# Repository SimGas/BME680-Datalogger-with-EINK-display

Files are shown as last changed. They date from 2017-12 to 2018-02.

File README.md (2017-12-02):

# BME680-Datalogger-with-EINK-display
Datalogger with BME680-Sensor, EINK Display, RTC and µSD-Storage

This project features a Arduino based datalogger reading temperature, relative humidity, pressure and IAQ values from a Bosch BME680 sensor. It displays the data at a 2.9 inch waveshare e-ink display using olikraus's u8g2 lib. The data is being synchronized with a DS3231 RTC and stored at a micro SD-Card.

The whole system runs on a adafruit feather M0 board

Please consider that this project is in a very early development status. I haven't completed the program code yet and I've just ordered the Mainboard.
If you want to make your own copy of this project, please contact me for information about recent unpublished changes.

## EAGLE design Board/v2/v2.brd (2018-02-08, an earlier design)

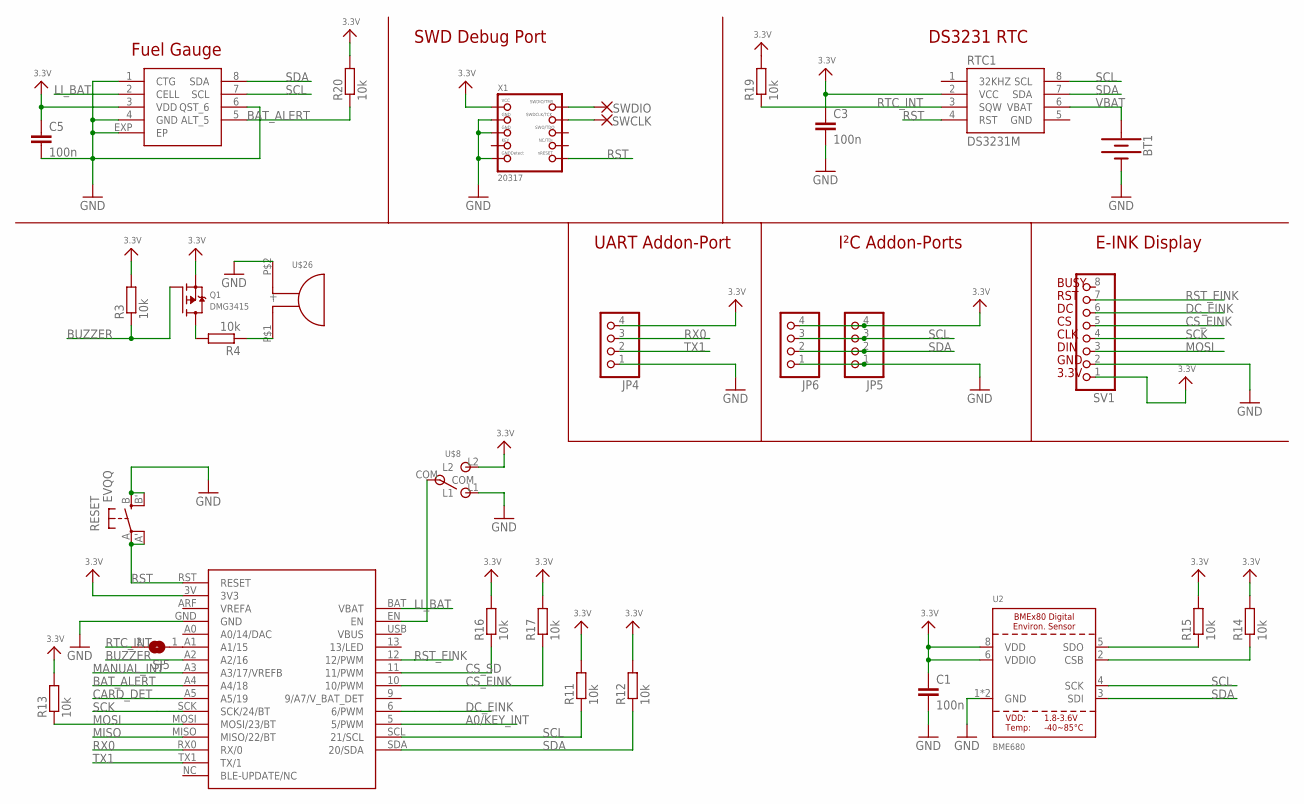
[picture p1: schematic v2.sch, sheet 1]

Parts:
BT1: BATTERY-12MM_SMD; BATTCON_12MM
C1, C3, C5: 100n; C0805
JP4, JP5, JP6: PINHD-1X04_2.54; 1X04
Q1: DMG3415; SOT23-WIDE
R3, R4, R11, R12, R13, R14, R15, R16, R17, R19, R20: 10k; R0805
RESET: EVQQ; EVQ-Q2
RTC1: DS3231M; SO08
SJ5: SOLDERJUMPERCLOSED; SOLDERJUMPER_CLOSEDWIRE
SV1: PINHD-1X08_2.54; 1X08
SWCLK: SMD1,27-2,54
SWDIO: SMD1,27-2,54
U2: BME680; BME280
U$8: MSK-12C02_SMD_SPDT_SWITCH; MSK-12C02
U$15: FEATHER_M0
U$26: DTS402G1; DET402G1
U$33: MAX17043; DFN-2X3
X1: 20317; 2X05_1.27MM_BOX_POSTS

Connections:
3.3V: C1.1, C3.1, C5.1, JP4.4, JP5.4, JP6.4, Q1.2 (S), R3.2, R11.2, R12.2, R13.2, R14.2, R15.2, R16.2, R17.2, R19.2, R20.2, RTC1.2 (VCC), SV1.1, U2.6 (VDDIO), U2.8 (VDD), U$8.L2, U$15.3V (3V3), U$33.3 (VDD), X1.1 (VCC); also elsewhere on the board
A0/KEY_INT: U$15.5 (5/PWM); also elsewhere on the board
BAT_ALERT: R20.1, U$15.A4 (A4/18), U$33.5 (ALT_5)
BUZZER: Q1.1 (G), R3.1, U$15.A2 (A2/16)
CARD_DET: U$15.A5 (A5/19); also elsewhere on the board
CS_EINK: R17.1, SV1.5, U$15.10 (10/PWM)
CS_SD: R16.1, U$15.11 (11/PWM); also elsewhere on the board
DC_EINK: SV1.6, U$15.6 (6/PWM)
EN: U$8.COM, U$15.EN
GND: BT1.GND (-), C1.2, C3.2, C5.2, JP4.1, JP5.1, JP6.1, RESET.B (S), RESET.B' (S1), RTC1.5 (GND), SV1.2, U2.1 (GND), U2.7 (GND), U$8.L1, U$15.GND, U$26.P$2 (-), U$33.1 (CTG), U$33.4 (GND), U$33.6 (QST_6), U$33.EXP (EP), X1.3 (GND), X1.5 (GND), X1.9 (GNDDETECT); also elsewhere on the board
LI_BAT: U$15.BAT (VBAT), U$33.2 (CELL)
MANUAL_INT: U$15.A3 (A3/17/VREFB); also elsewhere on the board
MISO: U$15.MISO (MISO/22/BT); also elsewhere on the board
MOSI: R13.1, SV1.3, U$15.MOSI (MOSI/23/BT); also elsewhere on the board
unnamed: R14.1, U2.2 (CSB)
unnamed: SJ5.1, U$15.A1 (A1/15)
unnamed: Q1.3 (D), R4.2
unnamed: R4.1, U$26.P$1 (+)
unnamed: R15.1, U2.5 (SDO)
unnamed: SWDIO.1, X1.2 (SWDIO)
unnamed: SWCLK.1, X1.4 (SWDCLK)
RST: RESET.A, RESET.A' (P1), RTC1.4 (RST), U$15.RST (RESET), X1.10 (NRESET)
RST_EINK: SV1.7, U$15.12 (12/PWM)
RTC_INT: R19.1, RTC1.3 (SQW), SJ5.2
RX0: JP4.3, U$15.RX0 (RX/0)
SCK: SV1.4, U$15.SCK (SCK/24/BT); also elsewhere on the board
SCL: JP5.3, JP6.3, R11.1, RTC1.8 (SCL), U2.4 (SCK), U$15.SCL (21/SCL), U$33.7 (SCL); also elsewhere on the board
SDA: JP5.2, JP6.2, R12.1, RTC1.7 (SDA), U2.3 (SDI), U$15.SDA (20/SDA), U$33.8 (SDA); also elsewhere on the board
TX1: JP4.2, U$15.TX1 (TX/1)
VBAT: BT1.PWR@1 (+), RTC1.6 (VBAT)

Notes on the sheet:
3.3V
GND
DIN
CLK
RST
BUSY
Fuel Gauge
SWD Debug Port
DS3231 RTC
E-INK Display
I²C Addon-Ports
UART Addon-Port

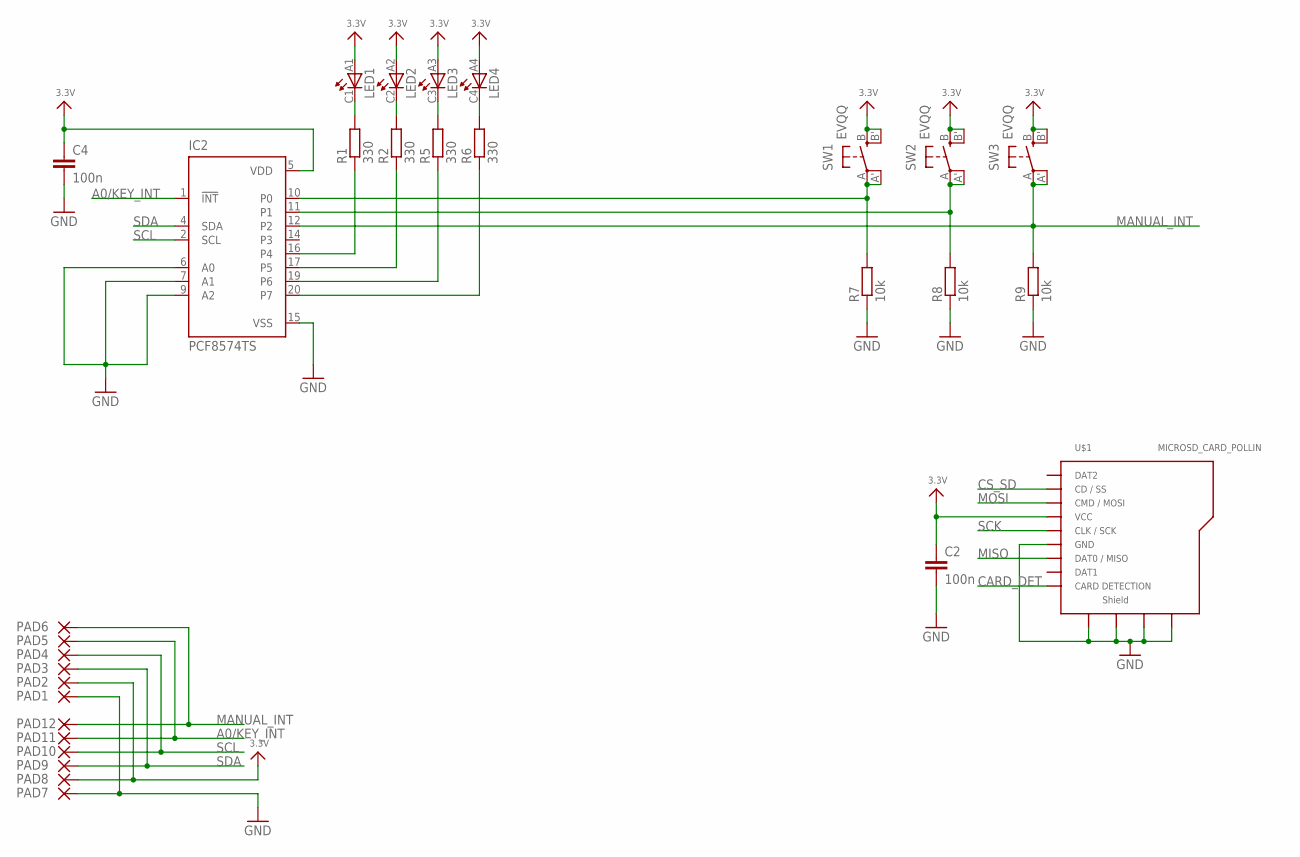
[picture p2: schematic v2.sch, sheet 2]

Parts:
C2, C4: 100n; C0805
IC2: PCF8574TS; SSOP20
PAD1, PAD2, PAD3, PAD4, PAD5, PAD6, PAD7, PAD8, PAD9, PAD10, PAD11, PAD12: SMD1,27-2,54
R1, R2, R5, R6: 330; R0805
R7, R8, R9: 10k; R0805
SW1, SW2, SW3: EVQQ; EVQ-Q2
U$1: MICROSD_CARD_POLLIN; MR**-AP*03**
U$5: LED_LIGHTGUIDE; LPA-C041301S-X

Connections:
3.3V: C2.1, C4.1, IC2.5 (VDD), PAD2.1, PAD8.1, SW1.B (S), SW1.B' (S1), SW2.B (S), SW2.B' (S1), SW3.B (S), SW3.B' (S1), U$1.VCC, U$5.A1, U$5.A2, U$5.A3, U$5.A4; also elsewhere on the board
A0/KEY_INT: IC2.1 (!INT), PAD5.1, PAD11.1; also elsewhere on the board
CARD_DET: U$1.CARD_DETECTION (CARD_D); also elsewhere on the board
CS_SD: U$1.DAT3/CS (CD/SS); also elsewhere on the board
GND: C2.2, C4.2, IC2.6 (A0), IC2.7 (A1), IC2.9 (A2), IC2.15 (VSS), PAD1.1, PAD7.1, R7.1, R8.1, R9.1, U$1.GND, U$1.SHD_1 (SHD1), U$1.SHD_2 (SHD2), U$1.SHD_3 (SHD3), U$1.SHD_4 (SHD4); also elsewhere on the board
MANUAL_INT: IC2.12 (P2), PAD6.1, PAD12.1, R9.2, SW3.A, SW3.A' (P1); also elsewhere on the board
MISO: U$1.DAT0 (DAT0/MISO); also elsewhere on the board
MOSI: U$1.CMD (CMD/MOSI); also elsewhere on the board
unnamed: IC2.16 (P4), R1.1
unnamed: IC2.17 (P5), R2.1
unnamed: IC2.10 (P0), R7.2, SW1.A, SW1.A' (P1)
unnamed: IC2.11 (P1), R8.2, SW2.A, SW2.A' (P1)
unnamed: IC2.19 (P6), R5.1
unnamed: IC2.20 (P7), R6.1
unnamed: R6.2, U$5.C4
unnamed: R5.2, U$5.C3
unnamed: R2.2, U$5.C2
unnamed: R1.2, U$5.C1
SCK: U$1.CLK (CLK/SCK); also elsewhere on the board
SCL: IC2.2 (SCL), PAD4.1, PAD10.1; also elsewhere on the board
SDA: IC2.4 (SDA), PAD3.1, PAD9.1; also elsewhere on the board

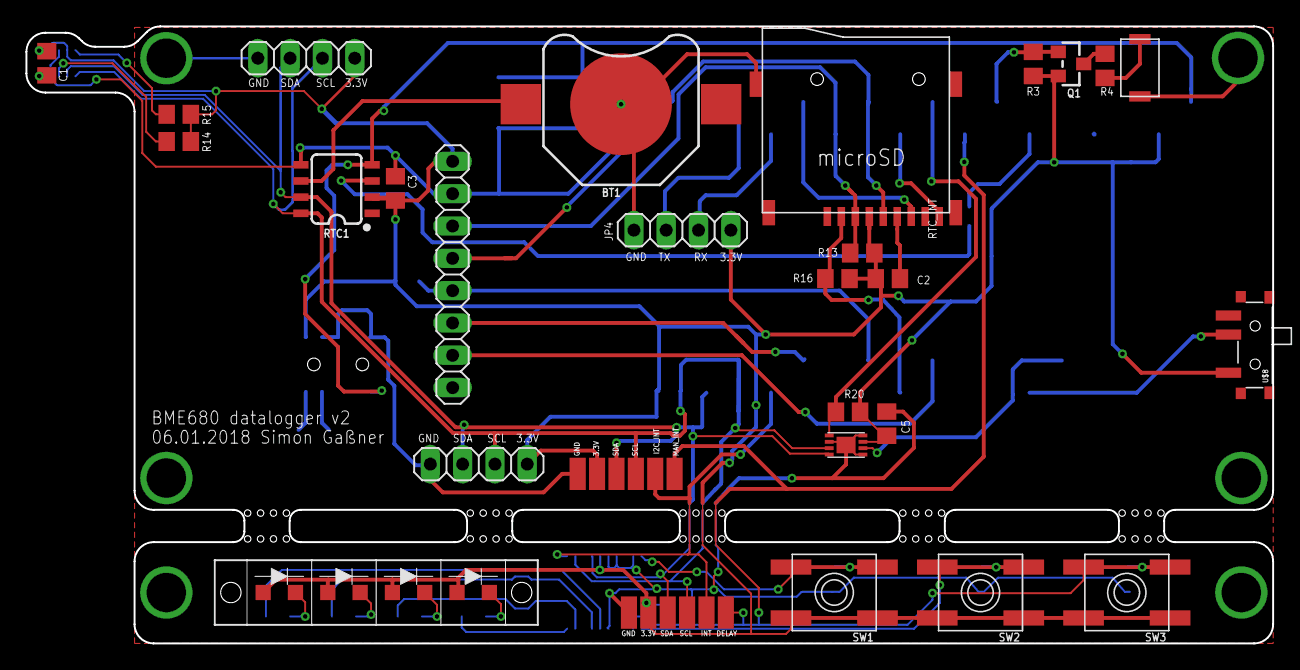
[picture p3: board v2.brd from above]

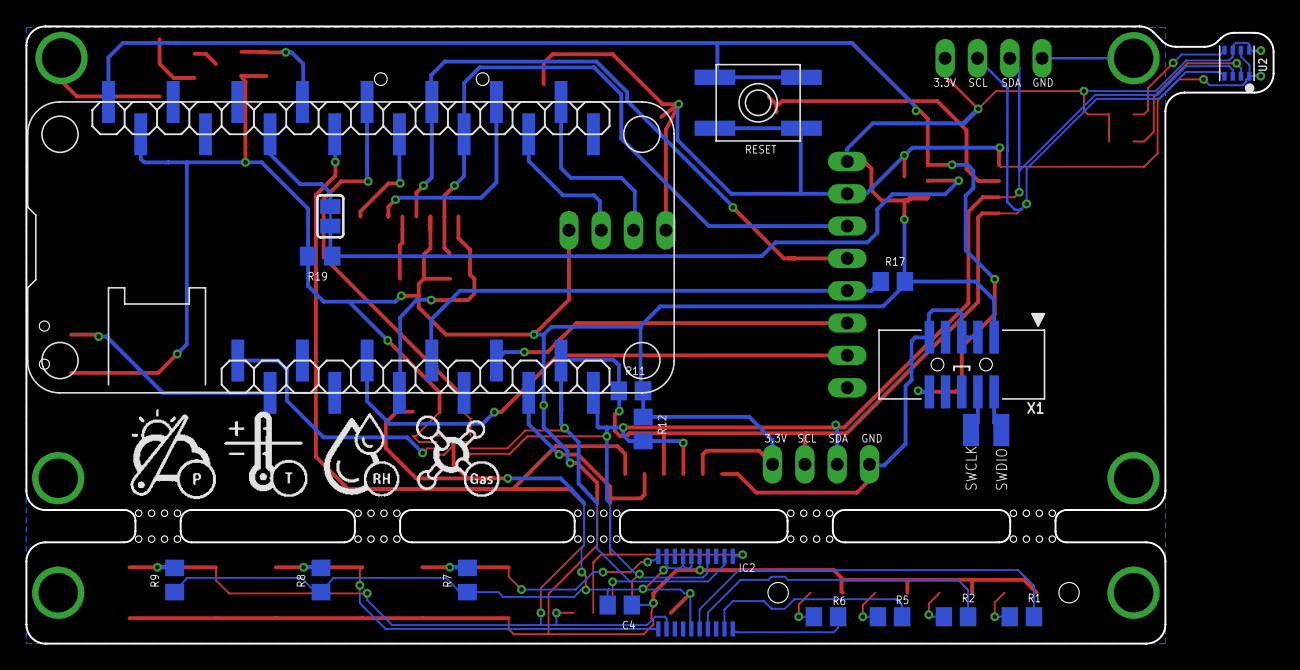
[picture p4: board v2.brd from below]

Board: 2 copper layers, 98.0 x 48.5 mm, 59 parts (20 on the bottom side), 40 nets.

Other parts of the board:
U$14: GASLOGO45MM; BME680_LOGO_30MM

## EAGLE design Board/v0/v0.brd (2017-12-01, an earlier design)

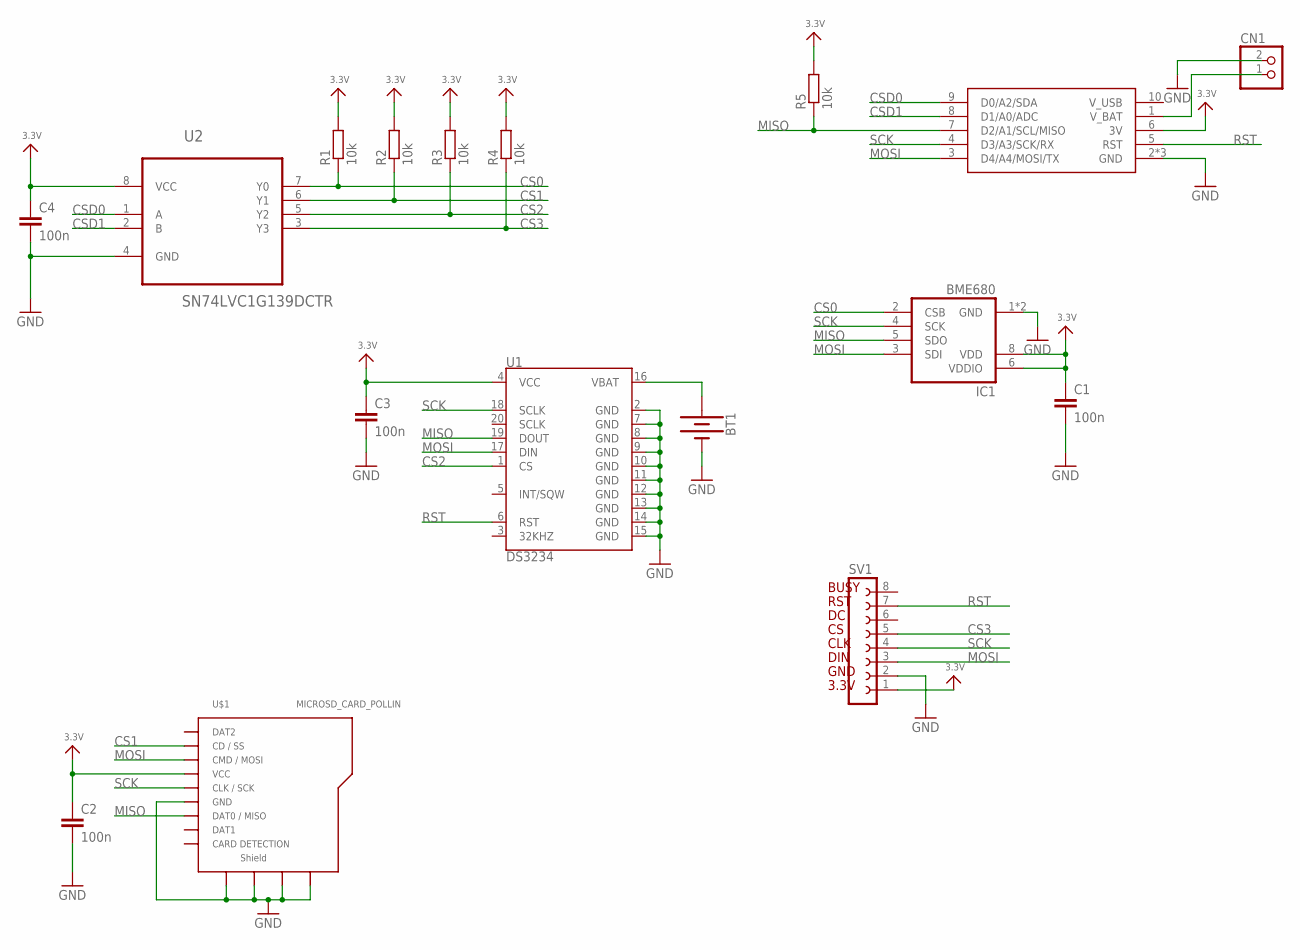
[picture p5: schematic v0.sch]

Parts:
BT1: BATTERY-12MM_SMD; BATTCON_12MM
C1, C2, C3, C4: 100n; C0805
CN1: JST_2PIN-SMT-RA; JST-PH-2-SMT-RA
IC1: BME680
R1, R2, R3, R4, R5: 10k; R0805
SV1: FE08-1; FE08
U1: DS3234; SO20-0.3
U2: SN74LVC1G139DCTR; SOP65P400X130-8N
U$1: MICROSD_CARD_POLLIN; MR**-AP*03**
U$8: TRINKET_M0

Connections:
3.3V: C1.1, C2.1, C3.1, C4.1, IC1.6 (VDDIO), IC1.8 (VDD), R1.2, R2.2, R3.2, R4.2, R5.2, SV1.1, U1.4 (VCC), U2.8 (VCC), U$1.VCC, U$8.6 (3V)
CS0: IC1.2 (CSB), R1.1, U2.7 (Y0)
CS1: R2.1, U2.6 (Y1), U$1.DAT3/CS (CD/SS)
CS2: R3.1, U1.1 (CS), U2.5 (Y2)
CS3: R4.1, SV1.5, U2.3 (Y3)
CSD0: U2.1 (A), U$8.9 (D0/A2/SDA)
CSD1: U2.2 (B), U$8.8 (D1/A0/ADC)
GND: BT1.GND (-), C1.2, C2.2, C3.2, C4.2, CN1.2 (1), IC1.1 (GND), IC1.7 (GND), SV1.2, U1.2 (GND), U1.7 (GND), U1.8 (GND), U1.9 (GND), U1.10 (GND), U1.11 (GND), U1.12 (GND), U1.13 (GND), U1.14 (GND), U1.15 (GND), U2.4 (GND), U$1.GND, U$1.SHD_1 (SHD1), U$1.SHD_2 (SHD2), U$1.SHD_3 (SHD3), U$1.SHD_4 (SHD4), U$8.2 (GND), U$8.11 (GND), U$8.12 (GND)
MISO: IC1.5 (SDO), R5.1, U1.19 (DOUT), U$1.DAT0 (DAT0/MISO), U$8.7 (D2/A1/SCL/MISO)
MOSI: IC1.3 (SDI), SV1.3, U1.17 (DIN), U$1.CMD (CMD/MOSI), U$8.3 (D4/A4/MOSI/TX)
unnamed: BT1.PWR@1 (+), U1.16 (VBAT)
RST: SV1.7, U1.6 (RST), U$8.5 (RST)
SCK: IC1.4 (SCK), SV1.4, U1.18 (SCLK), U$1.CLK (CLK/SCK), U$8.4 (D3/A3/SCK/RX)
V_BAT: CN1.1 (2), U$8.1 (V_BAT)

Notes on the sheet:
3.3V
GND
DIN
CLK
RST
BUSY

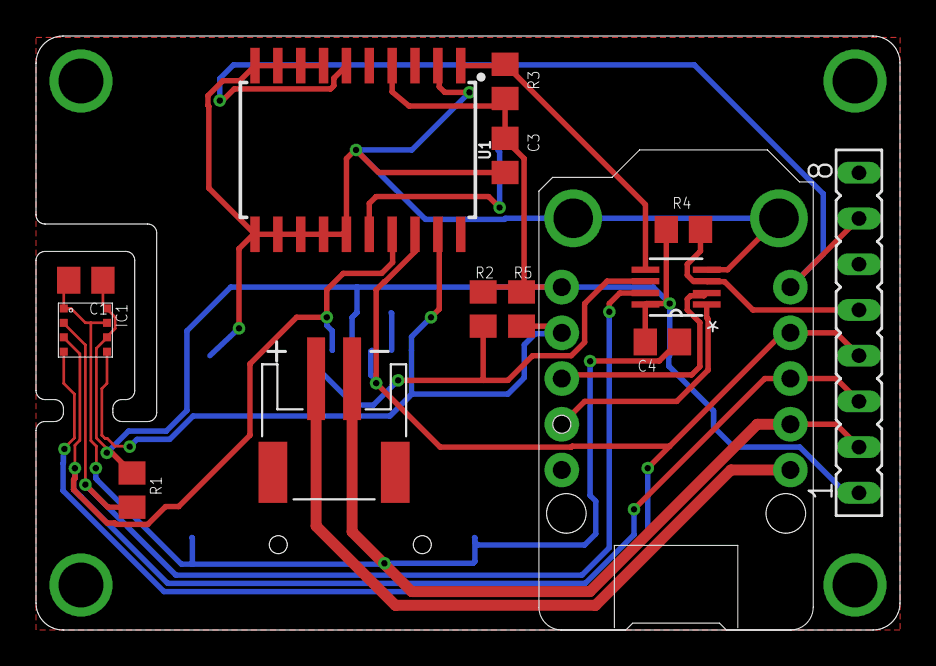
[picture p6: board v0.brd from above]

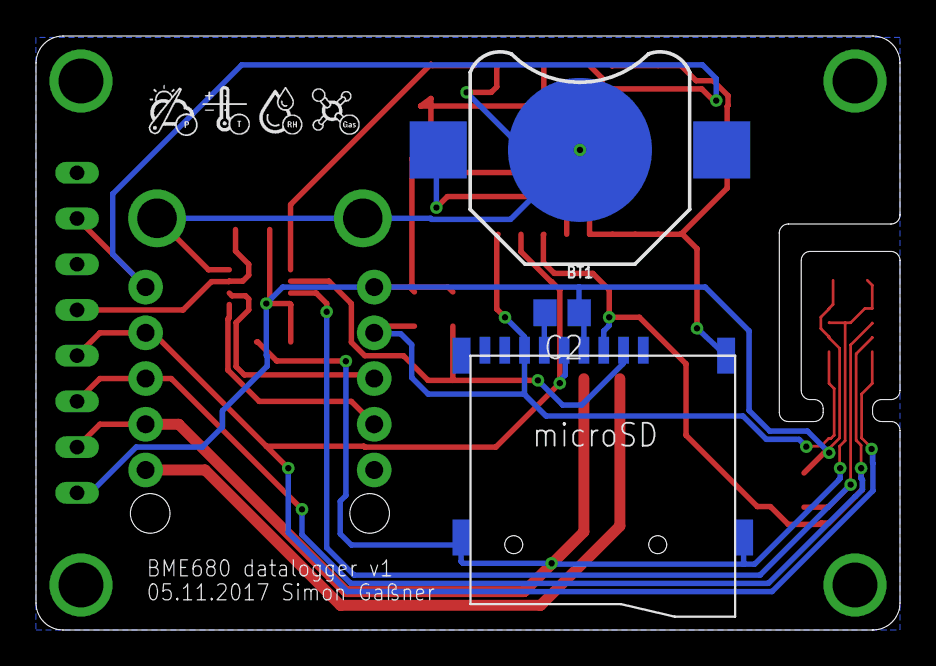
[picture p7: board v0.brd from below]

Board: 2 copper layers, 48.0 x 33.0 mm, 18 parts (4 on the bottom side), 14 nets.

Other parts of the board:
U$14: BME680_LOGO

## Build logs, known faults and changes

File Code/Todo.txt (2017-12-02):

safety shutdown for sd card at 0% remaining battery
implementing menu 
moving  values into graphs and modify position while playing
implement alarm and low power mode
implement 2 different alarms: second match and minute match
2 different loop routines for 2 different alarms:
	-taking data
	-taking data, averaging the last minute's values and write to display
implement bsec-library with IAQ or similar library(github favourites)
fix sd detection problem ? 
Set time <10 sec for first measurement (now.seconds +(10-now.seconds()%10)?
better sd file management: check if dayfile exists, don't write header then
replace all own timestamp routines by rtclib given ones

Notes
Standby mode of processor not possible, Use idle mode with everything deactivated, BME680 draws 0.9mA in low power mode(not ultra low power(t_response=92s!))

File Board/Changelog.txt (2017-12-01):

v2:
-fuel gauge (MAX17043
-delete tpl5110 option
add circuit to detect charging

v1:
-add battery voltage contact
-add button
-connected dc to GND(3-wire spi required -> change display jumper BS to 1)

-add tpl5110?
-Change to Feather M0
-add PFC8575C to expand boards (LEDs and buttons)

v0: Initial Release

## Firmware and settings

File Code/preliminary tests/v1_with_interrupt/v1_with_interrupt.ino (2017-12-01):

#include <Arduino.h>
#include <U8g2lib.h>
#include "voc_40.h"
#include "t_40.h"
#include "rh_40.h"
#include "p_40.h"
#include "sd_10.h"
#include <SPI.h>
#include <Wire.h>
#include <SdFat.h>     // SD-Library
#include <CircularBuffer.h>
#include <Adafruit_Sensor.h>
#include <Adafruit_BME280.h>
#include "RTClib.h"
//#define U8G2_16BIT
#define RST_EINK 12
#define DC_EINK 6
#define CS_EINK 10 
#define CS_SD 11
#define VBATPIN 9
#define RTC_INT 15 // For Arduino Zero, Pin number is required, not interrupt number 
#define SD_CardDetect 19

bool color = 1; //color switch. 1= black on white, 0 = white on black


const char daysOfTheWeek[7][12] = {"Sonntag", "Montag", "Dienstag", "Mittwoch", "Donnerstag", "Freitag", "Samstag"};
const char months[12][11] = {"Januar", "Februar", "März", "April", "Mai", "Juni", "Juli", "August","September", "Oktober", "November", "Dezember"};

Adafruit_BME280 bme;
//DS3231 rtc_alarm;
RTC_DS3231 rtc;
U8G2_IL3820_V2_296X128_F_4W_HW_SPI u8g2(U8G2_R0, CS_EINK, DC_EINK, RST_EINK );
SdFat SD;
CircularBuffer<int, 60> vocbuffer;
CircularBuffer<float, 60> tbuffer;
CircularBuffer<float, 60> hbuffer;
CircularBuffer<float, 60> pbuffer;
// End of constructor list
int graph_height = 38; //diagnostic initial values
int graph_width =64;
float maxvoc =0;
float minvoc =1000;
float maxt =0;
float mint =100;
float maxh =0;
float minh =100;
float maxp =0;
float minp =100;
bool warning= false;
bool interruptflag = false;
volatile bool interuptFlag = false;
int timetextshift=0;
String timestring = "123";
File datafile;
uint32_t logTime;
String timestamp = "";
String filename = "tempdata.csv";
volatile bool SLEEP_FLAG;
   DateTime now ; //has to be a global variable
void setup() {

 Serial.begin(115200);
 Serial.println("Program started, waiting 3 seconds for program to begin");


delay(3000); // wait for console opening
   pinMode(RTC_INT, INPUT_PULLUP);
  attachInterrupt(digitalPinToInterrupt(RTC_INT), ISR, FALLING);  // Attach interrupt to pin 6 with an ISR and when the pin state CHANGEs

  SYSCTRL->XOSC32K.reg |=  (SYSCTRL_XOSC32K_RUNSTDBY | SYSCTRL_XOSC32K_ONDEMAND); // set external 32k oscillator to run when idle or sleep mode is chosen
  REG_GCLK_CLKCTRL  |= GCLK_CLKCTRL_ID(GCM_EIC) |  // generic clock multiplexer id for the external interrupt controller
                       GCLK_CLKCTRL_GEN_GCLK1 |  // generic clock 1 which is xosc32k
                       GCLK_CLKCTRL_CLKEN;       // enable it
  while (GCLK->STATUS.bit.SYNCBUSY);              // write protected, wait for sync

  EIC->WAKEUP.reg |= EIC_WAKEUP_WAKEUPEN8;        // Set External Interrupt Controller to use channel 8 - pin 15

  
 // PM->SLEEP.reg |= PM_SLEEP_IDLE_CPU;  // Enable Idle0 mode - sleep CPU clock only
  //PM->SLEEP.reg |= PM_SLEEP_IDLE_AHB; // Idle1 - sleep CPU and AHB clocks
  PM->SLEEP.reg |= PM_SLEEP_IDLE_APB; // Idle2 - sleep CPU, AHB, and APB clocks

  // It is either Idle mode or Standby mode, not both. 
  //SCB->SCR |= SCB_SCR_SLEEPDEEP_Msk;   // Enable Standby or "deep sleep" mode

  SLEEP_FLAG = false; // begin awake




 
  pinMode(SD_CardDetect, INPUT);

 
 Wire.begin(); //needed for DS3231 library
  u8g2.begin();
  u8g2.setFont(u8g2_font_6x10_tr);
  u8g2.setDrawColor(color);
  u8g2.setPowerSave(1);
  bme.begin();
  vocbuffer.push(0); // Set beginning of graph to 0,0
  tbuffer.push(bme.readTemperature());
  hbuffer.push(bme.readHumidity());
  pbuffer.push(bme.readPressure() / 100.0F);
  
  
  //rtc.setAlarm1Simple(now.hour(), now.minute(), now.second() + 4);
  rtc.setA1Time(0, 0, 0, 10,0b00001110, false, false, false); /// 1110 means: Alarm, when seconds(10) match
  rtc.setA2Time(0, 0, 0, 0b1110000, false, false, false); //111 mens: Alarm every minute, at second 00
  rtc.turnOnAlarm(1);
  rtc.turnOnAlarm(2);
  now = rtc.now(); //Set initial time
  measureloop();
  displayloop(); // Run a first display loop to see something on the display

if (!SD.begin(CS_SD)) {
    Serial.println("Card failed, or not present");
    warning=1;
    // don't do anything more:
    return;                 //Don't place any SD-unrelated code below here:#################################################################################################################################################################
  }
  Serial.println("card initialized.");
  createfilename();
  writeheader();
}

void ISR(){//do nothing in here
  }


void dateTime(uint16_t* date, uint16_t* time) {
  DateTime now = rtc.now();
  // return date using FAT_DATE macro to format fields
  *date = FAT_DATE(now.year(), now.month(), now.day());
  // return time using FAT_TIME macro to format fields
  *time = FAT_TIME(now.hour(), now.minute(), now.second());
}


void createfilename(){
  DateTime now = rtc.now();
filename = String(now.year(),DEC);
filename += String(now.month()/10,DEC); //just for getting two characters per month: 2/3 -> 02/03
filename += String(now.month()%10,DEC);
filename += String(now.day()/10,DEC);
filename += String(now.day()%10,DEC);
filename += String(now.hour()/10,DEC);
filename += String(now.hour()%10,DEC);
filename += String(now.minute()/10,DEC);
filename += String(now.minute()%10,DEC);
filename += String(now.second()/10,DEC);
filename += String(now.second()%10,DEC);
filename += ".csv";
}
void writeheader() {
DateTime now = rtc.now();
String datastring = "test";
datastring = "Temperature Datalog \r\n";
//datafile.println(datastring);
datastring += "File created on: ";
datastring += String(now.month(),DEC);
datastring += "/";
datastring += String(now.day(),DEC);
datastring += "/";
datastring += String(now.year(),DEC);
datastring += "  , ";
datastring += String(now.hour(),DEC);
datastring += ":";
datastring += String(now.minute(),DEC);
datastring += ":";
datastring += String(now.second(),DEC);
datastring += "\r\n";

datastring += "Date;Time;U_Battery;Temperature;Humidity;Pressure";
SdFile::dateTimeCallback(dateTime);
datafile = SD.open(filename, FILE_WRITE);
datafile.println(datastring);
datafile.close();

}

void checkminmax(){ //reset maximum values and determine max storaged value
maxvoc=0; 
minvoc=1000;  
  maxt=0;
  mint=100; 
  maxh=0;
  minh=100;
  maxp=0;
  minp=1100;
for (int i=0; i < vocbuffer.size(); i++){
 if (vocbuffer[i] > maxvoc){maxvoc = vocbuffer[i];}
 if (vocbuffer[i] < minvoc){minvoc = vocbuffer[i];}
}
for (int i=0; i < tbuffer.size(); i++){
 if (tbuffer[i] > maxt){maxt = tbuffer[i];}
 if (tbuffer[i] < mint){mint = tbuffer[i];}
 if (maxt-mint < 1){maxt =maxt+0.5;mint=mint-0.5;}
}
for (int i=0; i < hbuffer.size(); i++){
 if (hbuffer[i] > maxh){maxh = hbuffer[i];}
 if (hbuffer[i] < minh){minh = hbuffer[i];}
 if (maxh-minh < 1){maxh =maxh+0.5;minh=minh-0.5;}
 //if (maxh >100){maxh=100;}

}
for (int i=0; i < pbuffer.size(); i++){
 if (pbuffer[i] > maxp){maxp = pbuffer[i];}
 if (pbuffer[i] < minp){minp = pbuffer[i];}
  if (maxp-minp < 1){maxp =maxp+0.5;minp=minp-0.5;}
}
}



void measureloop(){

  timestamp = String(now.month(),DEC);
  timestamp += "/";
  timestamp += String(now.day(),DEC);
  timestamp += "/";
  timestamp += String(now.year(),DEC);
  timestamp += ";";
  timestamp += String(now.hour()/10,DEC);
  timestamp += String(now.hour()%10,DEC);
  timestamp += ":";
  timestamp += String(now.minute()/10,DEC);
  timestamp += String(now.minute()%10,DEC);
  timestamp += ":";
  timestamp += String(now.second()/10,DEC);
  timestamp += String(now.second()%10,DEC);



  
vocbuffer.push(random(1,30));
  float temperature = bme.readTemperature();
  float humidity = bme.readHumidity();
  float pressure = (bme.readPressure()/ 100.0F);
  tbuffer.push(temperature);
  hbuffer.push(humidity);
  pbuffer.push(pressure);

  checkminmax();
  double measuredvbat = analogRead(VBATPIN);
measuredvbat *= 2;    // we divided by 2, so multiply back
measuredvbat *= 3.3;  // Multiply by 3.3V, our reference voltage
measuredvbat /= 1024; // convert to voltage
  String datastring = timestamp;
    datastring+= ";";
    datastring += String(measuredvbat,3);
    datastring+= ";";
    datastring+= temperature;
    datastring+= ";";
    datastring+= humidity;
    datastring+= ";";
    datastring+= pressure;


//if(warning==1 & digitalRead(SD_CardDetect)){SD.begin();Serial.println("looking for SD-card");}
if (datafile = SD.open(filename, FILE_WRITE)) {  
  datafile.println(datastring); //finish and write
  datafile.close();
  warning=0;
  }
  else {
    Serial.println("error opening datafile");
    warning=1;
  }
  if (!datafile.sync() || datafile.getWriteError()) {
    Serial.println("write error");
    warning=1;
  }
}

void displayloop(){
u8g2.setPowerSave(0);
 u8g2.clearBuffer();         // clear the internal memory
 u8g2.setDrawColor(not(color));
 u8g2.drawBox(0,0,296,128);
 u8g2.setDrawColor(color);
 drawgraph(75,47,'v');
 drawgraph(75,87,'t');
 drawgraph(223,47,'h');
 drawgraph(223,87,'p');
 drawvalue(0,10,'t');
 drawvalue(0,20,'v');
 drawvalue(0,30,'p');
 drawvalue(0,40,'h');
 drawtime();
 drawdate();
 drawstatus();
 u8g2.sendBuffer();         // transfer internal memory to the display
u8g2.setPowerSave(1); 
}





void loop() {
 // rtc.checkIfAlarm(1); //just reading alarm pin to reset the value before going to sleep
 // rtc.checkIfAlarm(2); //otherwise the interrupt won't be recognised as it's not changing
  
  now = rtc.now(); //Both loops need clock. now is initialized as global Datetime
  bool runmeasureloop = rtc.checkIfAlarm(1);
  bool rundisplayloop = rtc.checkIfAlarm(2);
    
    Serial.print(timestamp);
    Serial.println(" still running");
    if (runmeasureloop) {
          Serial.print(timestamp);
    Serial.print("  ");
    Serial.println("Sensorloop initiated");
   int second = now.second();
   int alarmsecond =0;
   if (second >= 50){alarmsecond=second-50;}
   else{alarmsecond = second+10;}
    rtc.setA1Time(0, 22, 13, alarmsecond, 0b1110, false,false, false);
    measureloop();
  }
  if (rundisplayloop) {
    Serial.print(timestamp);
    Serial.print("  ");
    Serial.println("Displayloop initiated");
     displayloop();
  }
//  delay(500);
__WFI(); // wait for interrupt
}






void drawtime(){
timestring  = String((now.hour()/10), DEC);
timestring += String(now.hour()%10, DEC);
timestring += ':';
timestring += String(now.minute()/10, DEC);
timestring += String(now.minute()%10, DEC);
//timestring += ':';
//timestring += String(now.second()/10, DEC);
//timestring += String(now.second()%10, DEC);
char timechar[6] ;
timestring.toCharArray(timechar, 6);
  u8g2.setFont(u8g2_font_inb24_mf);
 int timex= u8g2.getStrWidth(timechar);
 u8g2.drawStr(148-0.5*timex , 25, timechar);
}

void drawstatus(){
if (warning==0){u8g2.drawXBM( 296-21-10, 0, sd_10_width, sd_10_height, sd_10_bits);} //draw SD status  
  int x = 296-19;
  int y = 0;
  int batstate =3;
    u8g2.drawFrame(x,y,17,10);
    u8g2.drawLine(295,3,295,6);
    u8g2.drawLine(294,2,294,7);
float measuredvbat = analogRead(VBATPIN);
measuredvbat *= 2;    // we divided by 2, so multiply back
measuredvbat *= 3.3;  // Multiply by 3.3V, our reference voltage
measuredvbat /= 1024; // convert to voltage
u8g2.setFont(u8g2_font_5x7_tr);
int batpercentage =0;
batpercentage = 205.16*measuredvbat-738,35; // conversion to battery percentage. linear approximation done by writing voltage to sd card and do a linear approximation with excel
if (batpercentage >100){batpercentage=100;}
else if (batpercentage <0){batpercentage =0;}
String batpercentagetext = String(batpercentage,DEC);
int textshift= u8g2.getStrWidth(batpercentagetext.c_str());
u8g2.setCursor(296-11-0.5*textshift,y+8); //center text in battery icon
u8g2.print(batpercentagetext);
}




void drawgraph(int x, int y, char parameter) {
  u8g2.drawLine(x, y, x, y+graph_height); //y-axis
  u8g2.drawTriangle(x,y, x-3,y+3, x+4,y+3); //arrowhead y-axis
  u8g2.drawLine(x,y+graph_height,x+graph_width, y+graph_height); //x-axis
  u8g2.drawTriangle(x+graph_width,y+graph_height, x+graph_width-2,y+graph_height-3, x+graph_width-2,y+graph_height+3);// arrowhead x-axis
  //u8g2.drawStr(x-22,y+graph_height-1+2, "123");   
  //u8g2.drawStr(x-22,y+6+5, "456");   //-5: half text height
 
  u8g2.drawStr( x+timetextshift-9, 200, "now");
 float mini=0;
 float maxi=0;
 double vocscaler = 1;//(1/graph_height)*(maxvoc-minvoc);

 float tscaler = float(31/(maxt-mint));//35 is the actual graph height, not the axis height
 float hscaler = float(31/(maxh-minh));
 float pscaler = float(31/(maxp-minp));

  switch (parameter){
    case 'v':
      u8g2.drawXBM( x-75, y, voc_40_width, voc_40_height, voc_40_bits); //draw picture
             
            
      for (int i=1; i < vocbuffer.size(); i++){
 
        u8g2.drawLine(x+i,y+graph_height-vocbuffer[i-1]/vocscaler,x+1+i,y+graph_height-vocbuffer[i]/vocscaler); // draw graph itself
        timetextshift=i;} // only has to be done for one of the graphs
        
      maxi=maxvoc;
      mini=minvoc;

      break;
    case 't':
      u8g2.drawXBM( x-75, y, t_40_width, t_40_height, t_40_bits); //draw picture
      for (int i=0; i < tbuffer.size(); i++){
        u8g2.drawLine(x+i,y+graph_height-1-int((tbuffer[i-1]-mint)*tscaler),x+1+i,y+graph_height-1-int((tbuffer[i]-mint)*tscaler));
        } // draw graph itself
      maxi=maxt;
      mini=mint;


      break;
    case 'h':
      u8g2.drawXBM( x-75, y, rh_40_width, rh_40_height, rh_40_bits); //draw picture
      for (int i=1; i < hbuffer.size(); i++){
        u8g2.drawLine(x+i,y+graph_height-1-int((hbuffer[i-1]-minh)*hscaler),x+1+i,y+graph_height-1-int((hbuffer[i]-minh)*hscaler)); } // draw graph itself
      maxi=maxh;
      mini=minh;

      break;
    case 'p':
      u8g2.drawXBM( x-75, y, p_40_width, p_40_height, p_40_bits); //draw picture
      for (int i=1; i < hbuffer.size(); i++){
        u8g2.drawLine(x+i,y+graph_height-1-int((pbuffer[i-1]-minp)*pscaler),x+1+i,y+graph_height-1-int((pbuffer[i]-minp)*pscaler)); } // draw graph itself
      maxi=maxp;
      mini=minp;

      break;

  }
    u8g2.drawLine(x,y+graph_height-1,x-3,y+graph_height-1); //draw line for min value
  u8g2.drawLine(x,y+6,x-3,y+6); //draw line for max value


  u8g2.setFont(u8g2_font_micro_tr);
  int textshift= u8g2.getStrWidth(String(mini).c_str());
  u8g2.setCursor(x-4-textshift,y+graph_height-1+2); //cursor for min value
  u8g2.print(mini);
  textshift= u8g2.getStrWidth(String(maxi).c_str());
  u8g2.setCursor(x-4-textshift,y+6+3); //cursor for min value
  u8g2.print(maxi);
}

void drawvalue(int x, int y, char parameter){
u8g2.setFont(u8g2_font_6x12_tf);
String currentvalue;
switch (parameter){
    case 'v':
      currentvalue = "IAQ: ";
      currentvalue += String(vocbuffer.last());
    break;
    case 't':
    currentvalue = "T: ";
      currentvalue += String(tbuffer.last(),2);
      currentvalue += "\xB0\C";
      break;
    case 'p':
    currentvalue = "p: ";
      currentvalue += String(pbuffer.last(),0);
      currentvalue += "mbar";
      break;
    case 'h':
      currentvalue = "rh: ";
      currentvalue += String(hbuffer.last(),1);
      currentvalue += "%";
      break;}
  u8g2.setCursor(x,y);
  u8g2.print(currentvalue); 
}

void drawdate(){
String datestring;
now = rtc.now();
datestring = daysOfTheWeek[now.dayOfTheWeek()];
datestring +=", ";
datestring += now.day();
datestring +=". ";
datestring +=months[now.month()-1];
datestring +=" ";
datestring +=now.year();
u8g2.setFont(u8g2_font_6x12_tf);
int textshift= u8g2.getStrWidth(String(datestring).c_str());
u8g2.setCursor(148-textshift/2,35); //cursor for min value
u8g2.print(datestring);
}

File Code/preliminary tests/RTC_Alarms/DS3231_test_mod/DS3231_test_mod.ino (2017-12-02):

/*
DS3231_test.pde
Eric Ayars
4/11

Test/demo of read routines for a DS3231 RTC.

Turn on the serial monitor after loading this to check if things are
working as they should.

*/

#include <DS3231.h>
#include <Wire.h>
#define RTC_INT 15

DS3231 Clock;
bool Century=false;
bool h12;
bool PM_time;
byte ADay, AHour, AMinute, ASecond, ABits;
bool ADy, A12h, Apm;
int interruptcounter=0;
void setup() {
	// Start the I2C interface
	Wire.begin();
	// Start the serial interface
	Serial.begin(9600);
// Test of alarm functions
    // set A1 to one minute past the time we just set the clock
    // on current day of week.
    //Clock.setA1Time(0, 22, 13, 10, 0b0001110, true,false, false); // Alarm 1 uses last four bit
    // set A2 to two minutes past, on current day of month.   // Alarm 2 uses first three bit
    //Clock.setA2Time(29, 22, 50, 0b1110000, false, false,false);
    // Turn on both alarms, with external interrupt
    Clock.turnOnAlarm(1);
    delay(1000);
    Clock.resetAlarmFlags();
    Clock.turnOffAlarm(2);
   pinMode(RTC_INT, INPUT_PULLUP);
   attachInterrupt(RTC_INT,inthandler, FALLING);
}

void inthandler(){
interruptcounter++;
  
}

void loop() {
	// send what's going on to the serial monitor.
	// Start with the year
  Serial.print("Interrupts so far:");
  Serial.println(interruptcounter);
	Serial.print("2");
	if (Century) {			// Won't need this for 89 years.
		Serial.print("1");
	} else {
		Serial.print("0");
	}
	Serial.print(Clock.getYear(), DEC);
	Serial.print(' ');
	// then the month
	Serial.print(Clock.getMonth(Century), DEC);
	Serial.print(' ');
	// then the date
	Serial.print(Clock.getDate(), DEC);
	Serial.print(' ');
	// and the day of the week
	Serial.print(Clock.getDoW(), DEC);
	Serial.print(' ');
	// Finally the hour, minute, and second
	Serial.print(Clock.getHour(h12, PM_time), DEC);
	Serial.print(' ');
	Serial.print(Clock.getMinute(), DEC);
	Serial.print(' ');
	Serial.print(Clock.getSecond(), DEC);
	// Add AM/PM indicator
	if (h12) {
		if (PM_time) {
			Serial.print(" PM ");
		} else {
			Serial.print(" AM ");
		}
	} else {
		Serial.print(" 24h ");
	}
	// Display the temperature
	Serial.print("T=");
	Serial.print(Clock.getTemperature(), 2);
	// Tell whether the time is (likely to be) valid
	if (Clock.oscillatorCheck()) {
		Serial.print(" O+");
	} else {
		Serial.print(" O-");
	}
	// Indicate whether an alarm went off
/*	if (Clock.checkIfAlarm(1)) {
		Serial.print(" A1!");
   int second = Clock.getSecond();
   int alarmsecond =0;
   if (second >= 50){alarmsecond=50-second;}
   else{alarmsecond = second+10;}
    Clock.setA1Time(0, 22, 13, alarmsecond, 0b1110, false,false, false);
	}
	if (Clock.checkIfAlarm(2)) {
		Serial.print(" A2!");
	}*/
	// New line on display
	Serial.print('\n');
	// Display Alarm 1 information
	Serial.print("Alarm 1: ");
	Clock.getA1Time(ADay, AHour, AMinute, ASecond, ABits, ADy, A12h, Apm);
	Serial.print(ADay, DEC);
	if (ADy) {
		Serial.print(" DoW");
	} else {
		Serial.print(" Date");
	}
	Serial.print(' ');
	Serial.print(AHour, DEC);
	Serial.print(' ');
	Serial.print(AMinute, DEC);
	Serial.print(' ');
	Serial.print(ASecond, DEC);
	Serial.print(' ');
	if (A12h) {
		if (Apm) {
			Serial.print('pm ');
		} else {
			Serial.print('am ');
		}
	}
	if (Clock.checkAlarmEnabled(1)) {
		Serial.print("enabled");
    
	}
	Serial.print('\n');
	// Display Alarm 2 information
	Serial.print("Alarm 2: ");
	Clock.getA2Time(ADay, AHour, AMinute, ABits, ADy, A12h, Apm);
	Serial.print(ADay, DEC);
	if (ADy) {
		Serial.print(" DoW");
	} else {
		Serial.print(" Date");
	}
	Serial.print(' ');
	Serial.print(AHour, DEC);
	Serial.print(' ');
	Serial.print(AMinute, DEC);
	Serial.print(' ');
	if (A12h) {
		if (Apm) {
			Serial.print('pm');
		} else {
			Serial.print('am');
		}
	}
	if (Clock.checkAlarmEnabled(2)) {
		Serial.print("enabled");
	}
	// display alarm bits
	Serial.print("\nAlarm bits: ");
	Serial.print(ABits, BIN);

	Serial.print('\n');
	Serial.print('\n');
	delay(1000);
}

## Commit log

2017-12-01 Intial Upload
    [v0.brd, v0.sch, v1.brd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]
2017-12-02 Optimization
    Optimization of readability
    Exchange of Strings with sprintf command
    reduced spi writing speed
2017-12-03 Implementing Sleep Mode
    I finally got the Sleep Mode (IDLE2) running on the Feather M0.
    I had to use a workaround for the __WFI instruction as I don't know how to mask EIC's yet.
    [v1.ino]
2018-02-08 Updating Board
    New version of board with several changes and new CCS811 sensor
    [v2.brd, v2.sch, v3.brd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]

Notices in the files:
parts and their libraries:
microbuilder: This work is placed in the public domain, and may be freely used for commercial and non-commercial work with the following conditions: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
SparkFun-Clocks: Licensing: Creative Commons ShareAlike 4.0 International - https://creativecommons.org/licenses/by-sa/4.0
